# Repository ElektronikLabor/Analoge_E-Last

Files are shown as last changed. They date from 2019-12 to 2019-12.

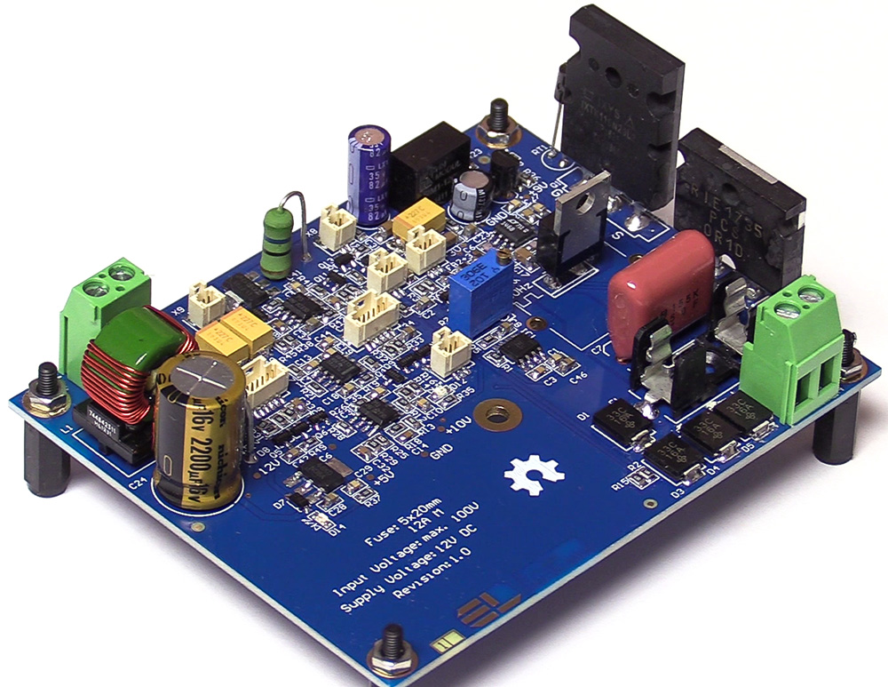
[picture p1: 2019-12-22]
Elektronik/E-Last_PCB_v1.0.jpg

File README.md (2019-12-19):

# Analoge_E-Last
Dies sind die Designdaten für eine analoge elektronische Last für 100V, 10A, 250W.
Das Projekt ist noch in Arbeit.

Der Schaltplan und das Layout sind erstellt mit dem Programm CircuitStudio von Altium

Weitere Infos: https://www.youtube.com/playlist?list=PLRvXcks5uT1ig3Mo9a-mfzwRX9TL_j7m5

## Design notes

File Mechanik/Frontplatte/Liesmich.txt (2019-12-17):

Bestellbar über https://www.schaeffer-ag.de

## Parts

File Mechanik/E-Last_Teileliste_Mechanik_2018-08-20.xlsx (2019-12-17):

 | Teileliste zur analogen E-Last
Pos. | Menge | Bezeichnung | Hersteller | Beschreibung | mögl. Lieferant | Best.-Nr. | Preis/Stk | Notitzen
1 | 1 | IP-6137 | Bud Industries | ABS-Gehäuse | DigiKey | IP-6137-ND | 25.42 €
2 | 1 |  | Schaeffer AG | Frontplatte | Schaeffer AG |  |  | Siehe Frontplatte_v0.1.fpd
3 | 1 | IRM-45-12ST | Mean Well | AC/DC-Wandler 12V 3,8A mit Schraubklemmen | Reichelt | MW IRM-45-12ST | 16.79 €
4 | 1 | WLPF20GR | Fischer Elektronik | Wärmeleitpaste, Metalloxydpulver, 10ml-Spritze | Reichelt | LEITPASTE 20GR | 4.40 €
5 | 1 | 930757100 | Hirschmann | Sicherheitspolklemme, 4 mm, schwarz | Reichelt | PKI 100 SW | 1.80 €
6 | 1 | 930757101 | Hirschmann | Sicherheitspolklemme, 4 mm, rot | Reichelt | PKI 100 RT | 1.80 €
7 | 1 | 10038545 | Fischer Elektronik | Hohlrippen-Lüfteraggregat 12 Volt DC | Reichelt | LA 6100 12V | 55.40 €
8 | 1 | 073392 | BKL | C8 Einbaustecker | Reichelt | B-AC 073392 | 1.60 €
9 | 2 | DPM 535/2 | Schwille | Einbaumessinstrument 2V | eBay
10 | 1 | LD 34 S | Knitter | Signalleuchte rot 2,2V | Distrelec | 300-39-844 | 7.29 €
11 | 1 | 1855.1108 | Marquardt | Wippschalter DPST 250V | Conrad | 700592 - 62 | 5.19 €
12 | 1 | M2012SS1W01 | NKK | Kippschalter SPDt 30V 3A M6 | DigiKey | 360-1801-ND | 3.02 €
13 | 1 | M2024SS1G01 | NKK | Kippschalter SP3T 30V M6 | DigiKey | 360-1856-ND | 6.15 €
14 | 1 | BT 81 6M | Atoms | Poti-Drehknopf 10-Gang 6mm | RS | 107-7253 | 12.08 €
15 | 1 | 3590s-002-502 | Bourns | 10-Gang-Potetiometer 0,25% | DigiKey | 3590S-2-502L-ND | 12.20 €
16 | 2 | 14.86.353 | Ettinger | Montagewinkel 12,0 x 15,0 x 1,5 mm | Ettinger | 14.86.353 | 2.18 €
17 |  | …
⁞

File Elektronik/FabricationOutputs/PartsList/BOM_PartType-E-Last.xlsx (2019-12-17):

E-Last |  |  |  |  |  | Component Count | 149 | 16.12.2019 | 19:43:20
# | Quantity | Designator | Value | Description | Manufacturer | PartNumber | Supplier 1 | Supplier Part Number 1 | Price [€]
1 | 13 | C1, C10, C11, C16, C18, C19, C27, C29, C31, C35, C41, C42, C44 | 100n | Cap Ceramic 0805 100n 25V | generic | generic
2 | 2 | C2, C36 | 220n | Cap Ceramic 0805 220n 50V | generic | generic
3 | 3 | C3, C12, C17 | 10n | Cap Ceramic 0805 10n 50V | generic | generic
4 | 3 | C4, C38, C39 | 330p | Cap Ceramic 0805 330p 50V | generic | generic |  |  | 0,18
5 | 2 | C5, C9 | 220p | Cap Ceramic 0805 220p 50V | generic | generic
6 | 1 | C6 | 100p | Cap Ceramic 0805 100p 50V | generic | generic
7 | 1 | C7 | 1µ5 | Cap Film 1µ5 250V 15mm | Panasonic | ECQE2155KF
8 | 5 | C8, C23, C33, C34, C46 | 1µ | Cap Ceramic 0805 1µ 25V | Samsung | CL21B105KAFNNNE | Digi-Key | 1276-1066-1-ND
9 | 1 | C13 | 1n5 | Cap Ceramic 0805 1n5 50V | generic | generic
10 | 2 | C14, C32 | 3n3 | Cap Ceramic 0805 3n3 50V | generic | generic
11 | 3 | C15, C21, C30 | 10µ | Cap Ceramic 1206 10µ 16V | Samsung | CL31B106MOHNNNE | Digi-Key | 1276-6641-1-ND | 0,13
12 | 1 | C20 | 100µ | Cap Elco 100µ Radial | Nichicon | UMA0J101MDD
13 | 3 | C22, C40, C43 | 220µ | Cap Tantal 220µ 16V SMD | AVX | TPSE227*016#0100 | Reichelt | TPS 7343 220/16 | 1,15
14 | 1 | C24 | 2200µ | Cap Elco 2200µ 16V THT Radial | Rubycon | UFW1C222MHD | Digi-Key | 493-15122-ND | 0.77
15 | 1 | C25 | 82µ | Cap Elco 82µ Radial | Nippon Chemi-Con | ELXY350ETD820MF15D
16 | 2 | C26, C28 | 330n | Cap Ceramic 0805 330n 50V | Samsung | CL21B334KBFNNNE | Digi-Key | 1276-1123-1-ND | 0,18
17 | 1 | C37 | 4µ7 | Cap Ceramic 0805 4µ7 10V | generic | generic
18 | 1 | C45 | 1n | Cap Ceramic 0805 1n 50V | generic | generic
19 | 4 | D1, D3, D4, D5 | 1.5SMC33CA | Diode, TVS, Bi, 33V, 33A, DO-214AB | Littelfuse | 1.5SMC33CA
20 | 1 | D2 | 12TQ150 | Diode Schottky, 150V, 15A, TO-220-2 | SMC | 12TQ150 | Digi-Key | 1655-1002-ND | 0,61
21 | 2 | D6, D7 | BAV19W | Diode, Fast, 400mA, SOD-123, SMD | Diodes | BAV19W-E3-08
22 | 1 | D8 | 1.5KE22A | Diode, TVS, Uni, 22V, CB429, THT | ST | 1.5KE22A | Reichelt | 1,5KE 22A
23 | 1 | D9 |  | LED Red 0805 SMD | Würth Elektronik | 150080SS75000 | Digi-Key | 732-4985-1-ND | 0,18
24 | 1 | D10 | 10V | V-Ref LM4040AIM3-10.0 | Texas Instruments | LM4040AIM3-10.0/NOPB | Digi-Key | LM4040AIM3-10.0/NOPBCT-ND | 1,53
25 | 3 | D11, D13, D14 |  | LED Blue 0805 SMD | Würth Elektronik | 150080BS75000 | Digi-Key | 732-4982-1-ND | 0,18
26 | 1 | D12 |  | LED Green 0805 SMD | Generic | Generic
27 | 1 | F1 | 12A | Fuse w Holder 5x20mm 25mm 12A THT | Schurter | 0031.8211 | Reichelt | PL OGN-25 | 0,44
28 | 3 | FB1, FB2, FB3 | 1k | Ferrite Bead 0805 1k 100MHz | Murata | BLM21AG102SN1 | Reichelt | BLM21AG 102
29 | 1 | HS1 |  | Mech Heat Sink CK960/20/SE TO-220; Unfertig | Alutronic | CK960/20/SE | Reichelt | V CK960/20
30 | 1 | IC1 | ICM7555 | Timer ICM7555 8-SOIC | Intersil | ICM7555IBA | Reichelt | ICM 7555 IBAZ
31 | 1 | IC2 | LT1468 | OpAmp LT1468 1x 90MHz | Linear Technology | LT1468CS8 | Reichelt | LT 1468 CS8 | 7,05
32 | 2 | IC3, IC7 | LM393 | Comparator LM393DT 2x | ST | LM393DT | Digi-Key | 497-1593-1-ND | 0,44
33 | 1 | IC4 | TL072C | OpAmp TL072CD 2x JFET 3MHz | Texas Instruments | TL072CD
34 | 1 | IC5 | 78L09 | Voltage Regulator 9V | ST | L78L09ACZ
35 | 1 | IC6 | LM1117 | Voltage Regulator 5V SOT-223 | Texas Instruments | L7805CV | Reichelt | LM 1117 MPX-5.0
36 | 1 | L1 | 110µ | Common Mode Choke, WE-CMB Type S, 110 uH | Würth Elektronik | 744842311
37 | 1 | L2 | 12µ | Inductor 12µ 7447669112 SMD | Würth Elektronik | 7447669112 | Digi-Key | 732-7321-1-ND | 0,43
38 | 1 | Q1 | IXTK110N20L2 | Transistor n-MOS, TO-264, 200V, THT | IXYS | IXTK110N20L2 | Digi-Key | IXTK110N20L2-ND | 24,00
39 | 11 | Q2, Q3, Q4, Q5, Q6, Q7, Q8, Q9, Q10, Q11, Q13 |  | Transistor n-MOS SOT-23 30V Vgs=20V | ON Semiconductor | NDS355AN | Digi-Key | NDS355ANCT-ND | 0,39
40 | 1 | Q12 | IRLL2705 | Transistor n-MOS SOT-223 55V Vgs=16V | International Rectifier | IRLL2705PbF | Reichelt | IRLL 2705 | 0,44
41 | 7 | R1, R11, R14, R20, R26, R39, R41 | 18k | Resistor 0805 18k | generic | generic
42 | 2 | R2, R45 | 5k1 | Resistor 0805 5k1 | generic | generic
43 | 2 | R3, R36 | 5k6 | Resistor 0805 5k6 | generic | generic
44 | 1 | R4 | 100R | Resistor 0805 100R | generic | generic
45 | 2 | R5, R34 | 6k8 | Resistor 0805 6k8 | generic | generic
46 | 2 | R6, R44 | 39k | Resistor 0805 39k | generic | generic
47 | 1 | R7 | 1k | Pot 1k THT 30 turns | Suntan | TSR-3296-Y-102-R
48 | 1 | R8 | 10R | Resistor 0805 10R | generic | generic
49 | 2 | R9, R16 | 1k | Resistor 0805 1k | generic | generic
50 | 1 | R10 | 0R1 | Resistor 4-SIL 0R1 0.5% 40W | Riedon | PCS-0R1D1 | Digi-Key | 696-1749-ND | 15,91
51 | 1 | R12 | 5M6 | Resistor 0805 5M6 | generic | generic
52 | 1 | R13 | 91k | Resistor 0805 91k | generic | generic
53 | 1 | R15 | 1M8 | Resistor 0805 1M8 | generic | generic
54 | 2 | R17, R21 | 200k | Resistor 0805 200k | generic | generic
55 | 3 | R18, R47, R49 | 1k8 | Resistor 0805 1k8 | generic | generic
56 | 2 | R19, R37 | 2k | Resistor 0805 2k | generic | generic
57 | 1 | R22 | 2R2 | Resistor 0805 2R2 | generic | generic
58 | 1 | R23 | 220R | Resistor 0805 220R | generic | generic
59 | 1 | R24 | 270R | Resistor 0805 270R | generic | generic
60 | 1 | R25 | 62k | Resistor 0805 62k | generic | generic
61 | 1 | R27 | 4M3 | Resistor 0805 4M3 | generic | generic
62 | 1 | R28 | 10M | Resistor 0805 10M | generic | generic
63 | 2 | R29, R50 | 15k | Resistor 0805 15k | generic | generic
64 | 6 | R30, R31, R32, R33, R35, R42 | 4k7 | Resistor 0805 4k7 | generic | generic
65 | 2 | R38, R40 | 10k | Resistor 0805 10k | generic | generic
66 | 1 | R43 | 82k | Resistor 0805 82k | generic | generic
67 | 1 | R46 | 6k98 | Resistor 0805 6k98 | generic | generic
68 | 1 | R48 | 56R | Resistor 56R 2W THT | VITROHM | PO593-0 5 T 56R | Reichelt | 2W METALL 56 | 0,11
69 | 1 | R51 | 4M7 | Resistor 0805 4M7 | generic | generic
70 | 1 | RT1 | 2k | Sensor Temp 2k TO92-2 | NXP | KTY81/222 | Conrad | 181048 - 62 | 2,05
71 | 1 | VR1 | SIM1-1203 | DC/DC Converter Isolated 3V | HN Electronic Components | SIM1-1203-SIL4
72 | 3 | X1, X2, X3 | T1M-03-F-SV-L | Connector, Male, Vertical, 3-Pin, 1mm, SMD | SAMTEC | T1M-03-F-SV-L | SAMTEC | T1M-03-F-SV-L
73 | 2 | X4, X5 |  | Terminal, 2-Pin, 5.08mm, THT | RND connect | RND 205-00287 | Reichelt | RND 205-00287 | 0,41
74 | 2 | X6, X7 | T1M-06-F-SV-L | Connector, Male, Vertical, 6-Pin, 1mm, SMD | SAMTEC | T1M-06-F-SV-L | SAMTEC | T1M-06-F-SV-L
75 | 2 | X8, X9 | T1M-02-F-SV-L | Connector, Male, Vertical, 2-Pin, 1mm, SMD | SAMTEC | T1M-02-F-SV-L | SAMTEC | T1M-02-F-SV-L

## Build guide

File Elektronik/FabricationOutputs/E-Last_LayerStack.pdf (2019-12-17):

Layer | Board Layer Stack | Name | Material | Thickness | Constant

# Board Stack Report

Stack Up | Layer Stack

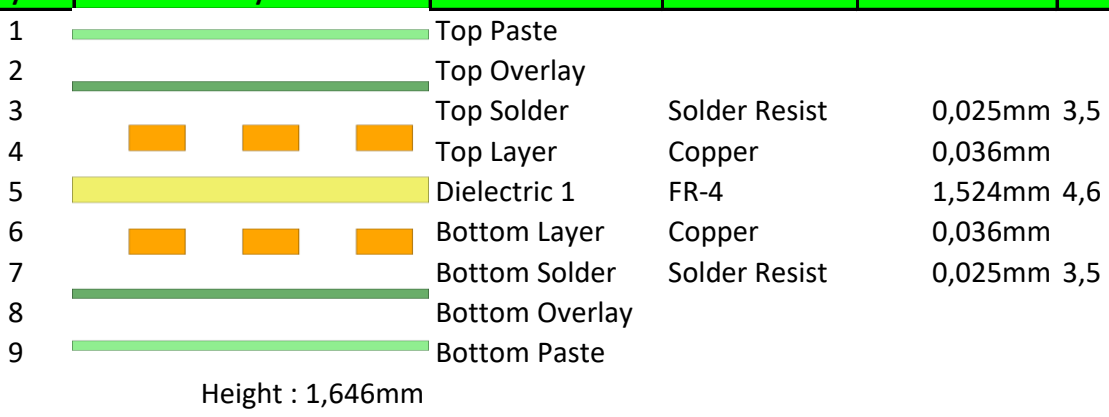
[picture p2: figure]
Top Paste; Top Overlay; Top Solder; Solder Resist; Top Layer; Copper; Dielectric 1; Bottom Layer; Bottom Solder; Bottom Overlay; Bottom Paste; Height : 1,646mm

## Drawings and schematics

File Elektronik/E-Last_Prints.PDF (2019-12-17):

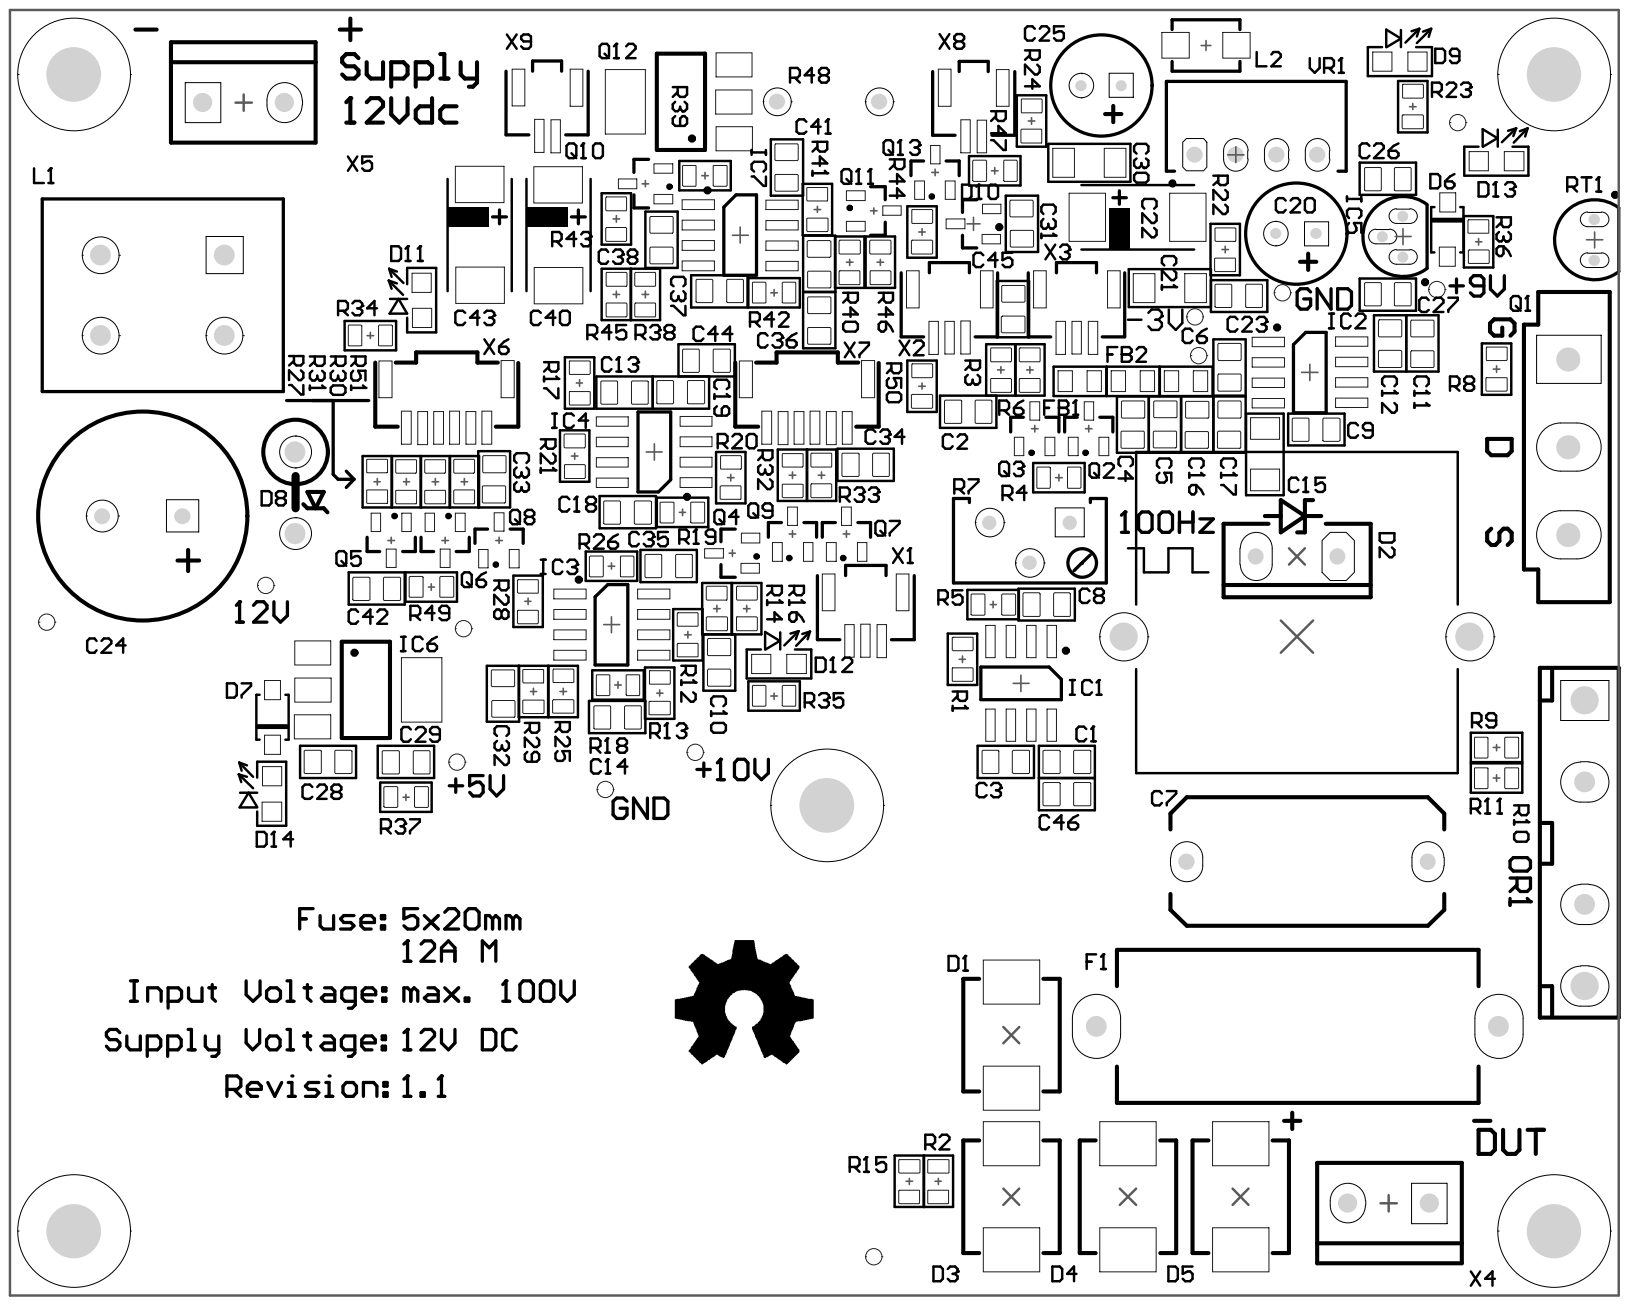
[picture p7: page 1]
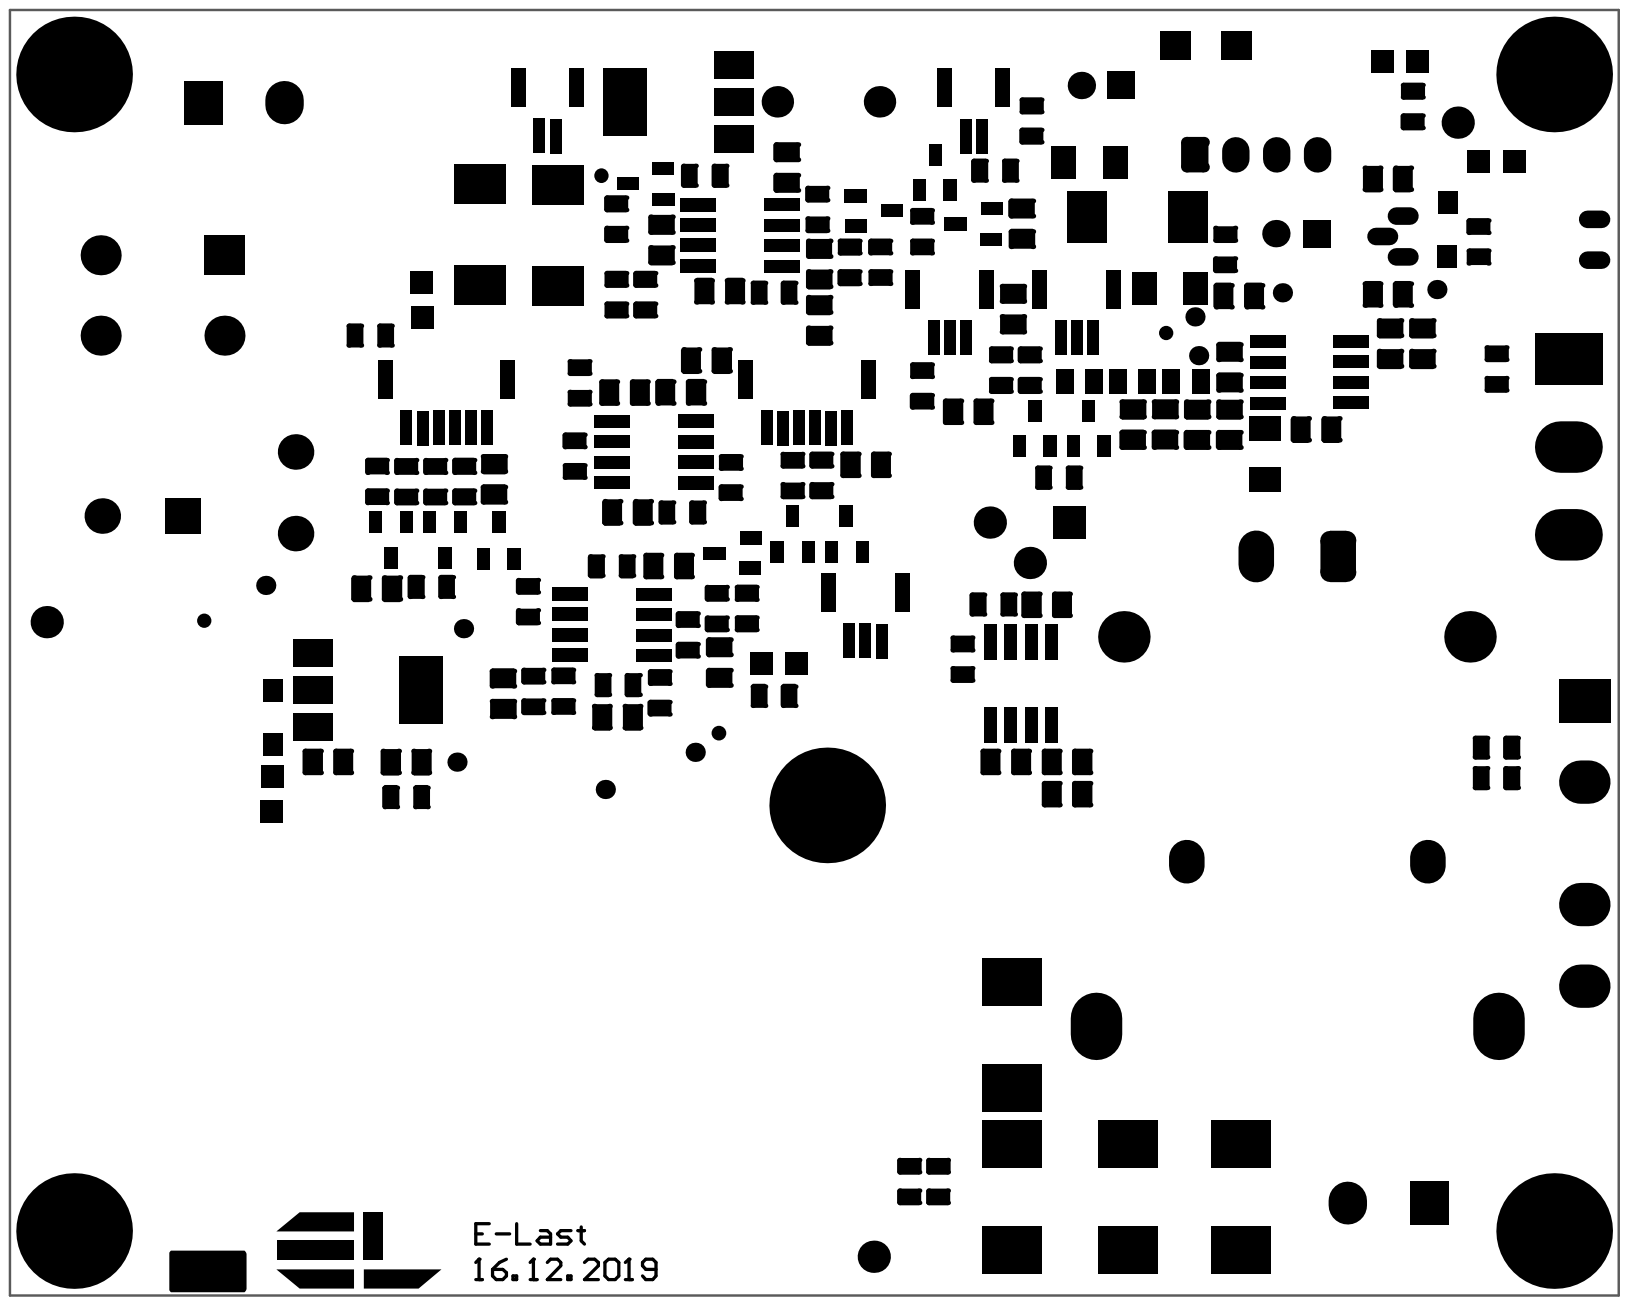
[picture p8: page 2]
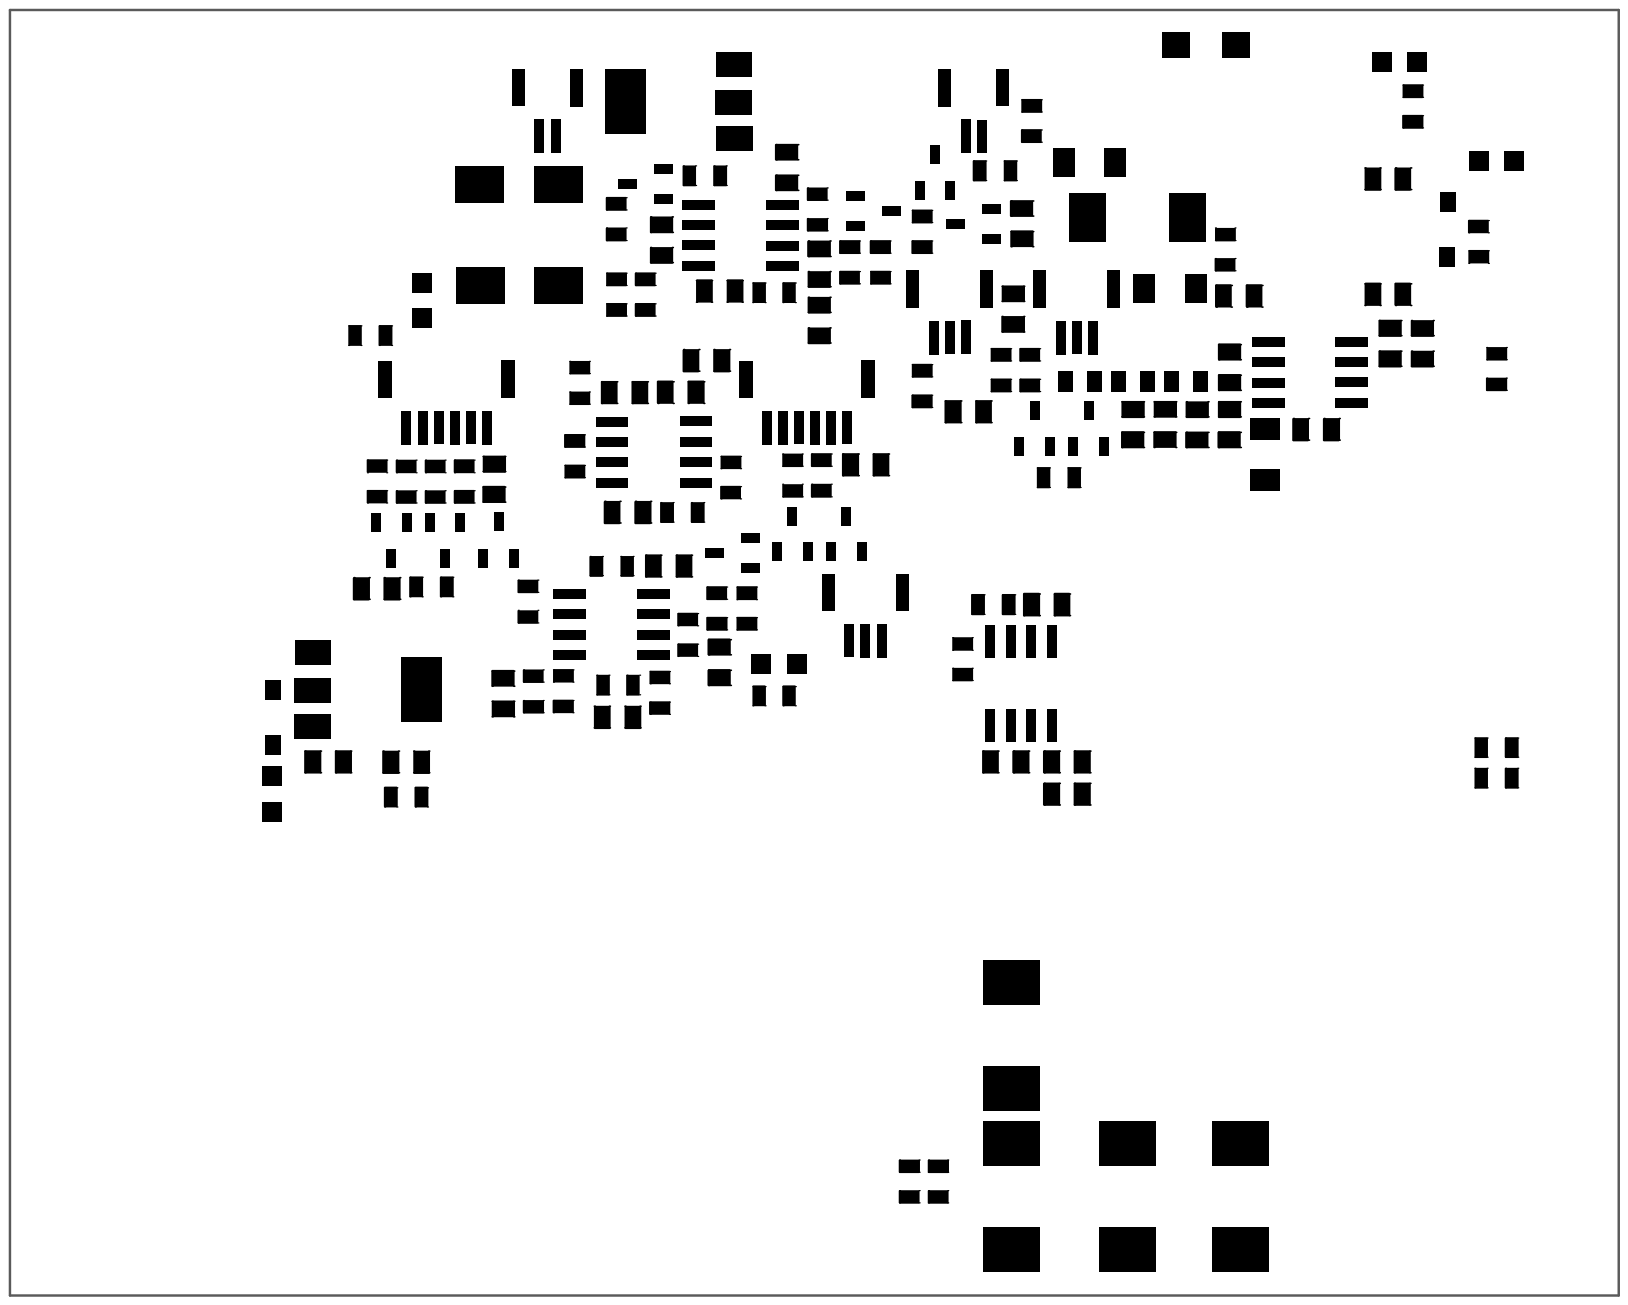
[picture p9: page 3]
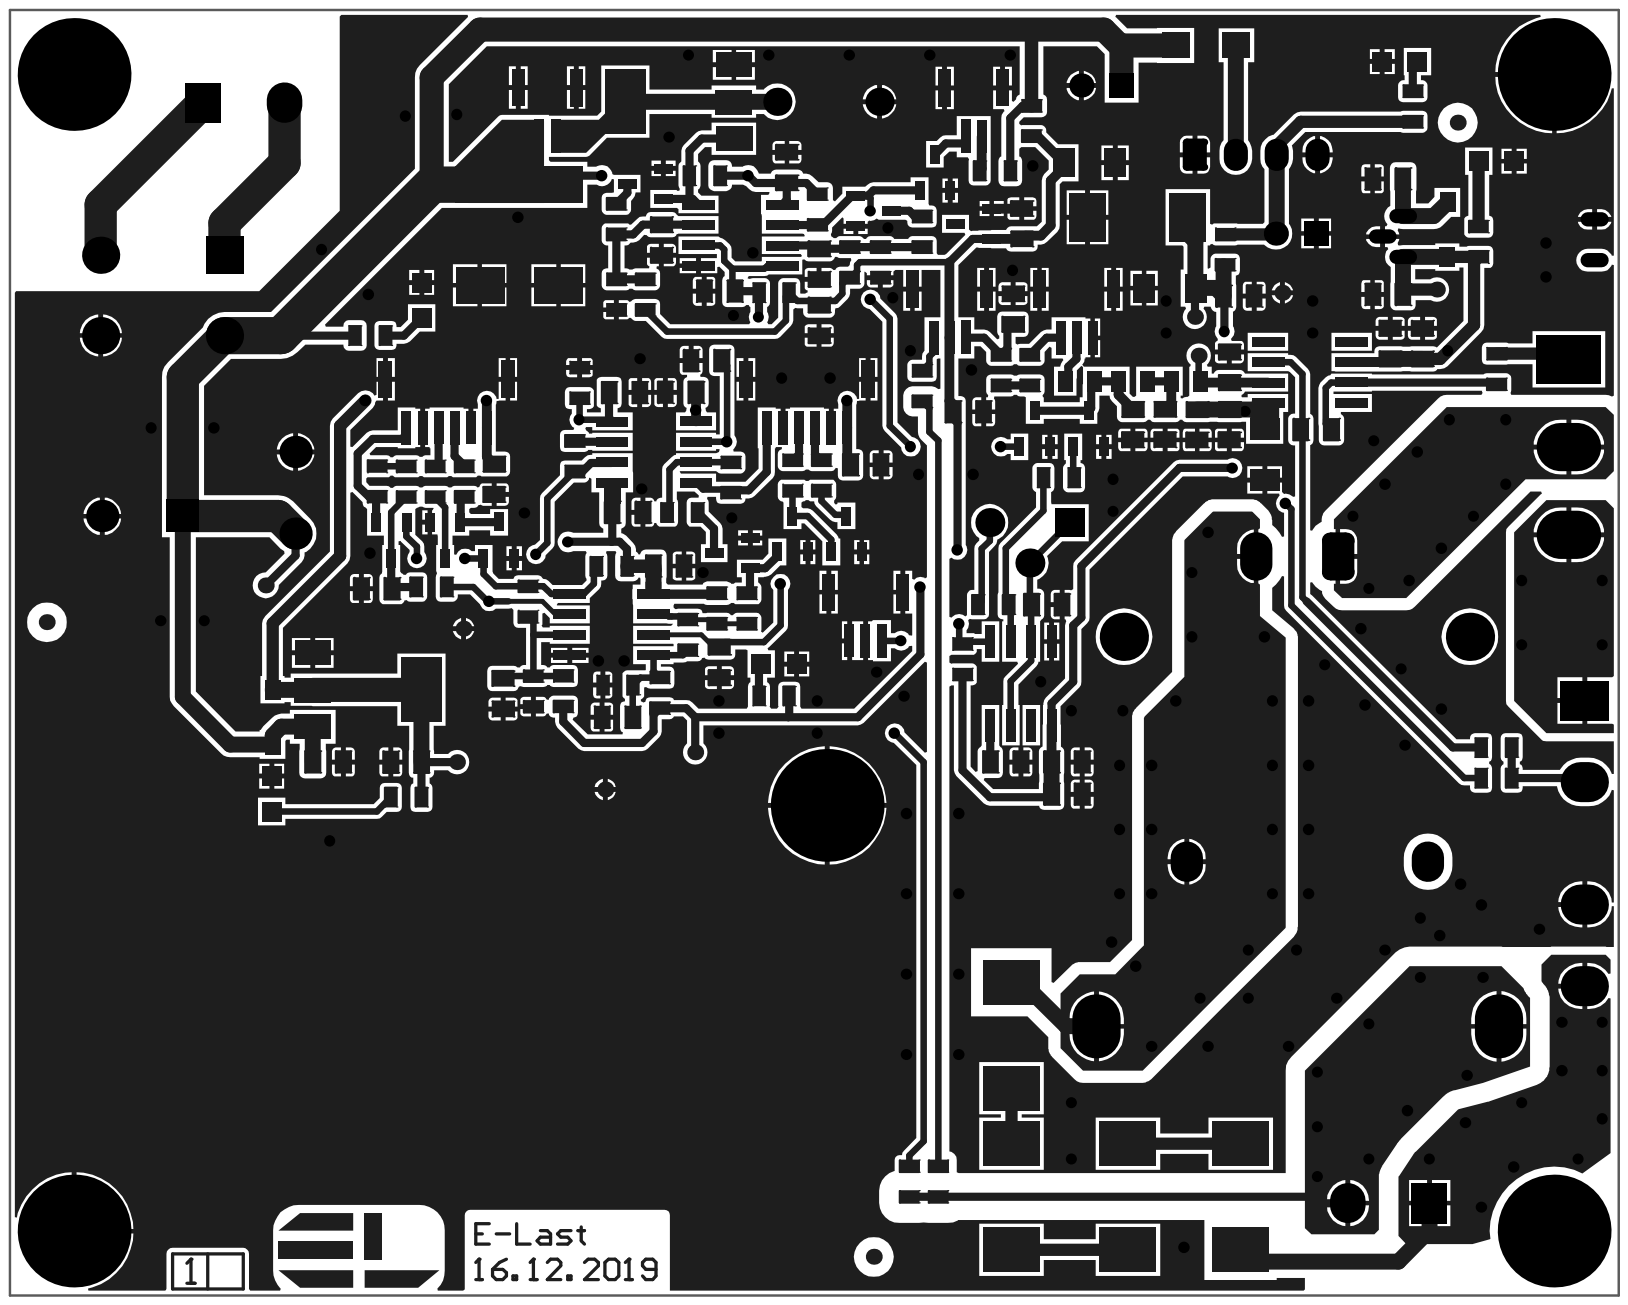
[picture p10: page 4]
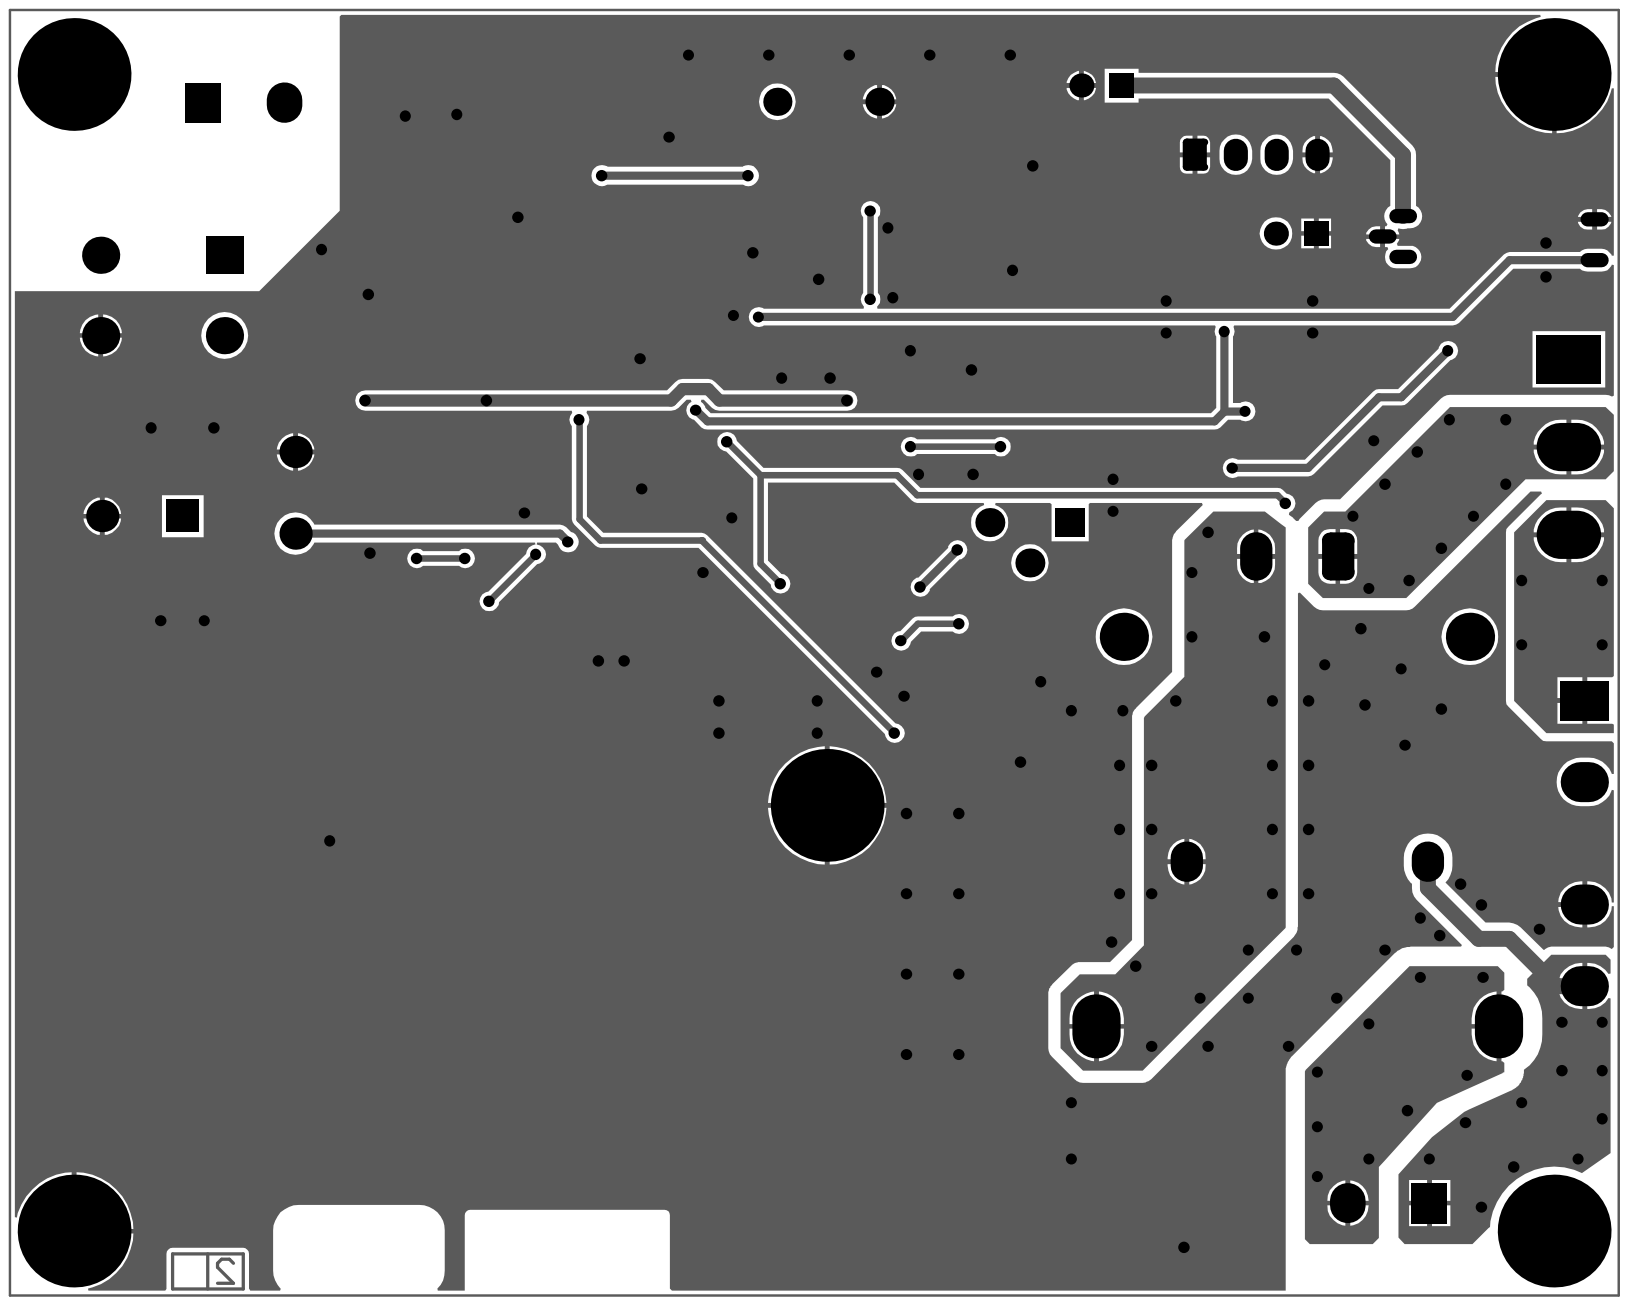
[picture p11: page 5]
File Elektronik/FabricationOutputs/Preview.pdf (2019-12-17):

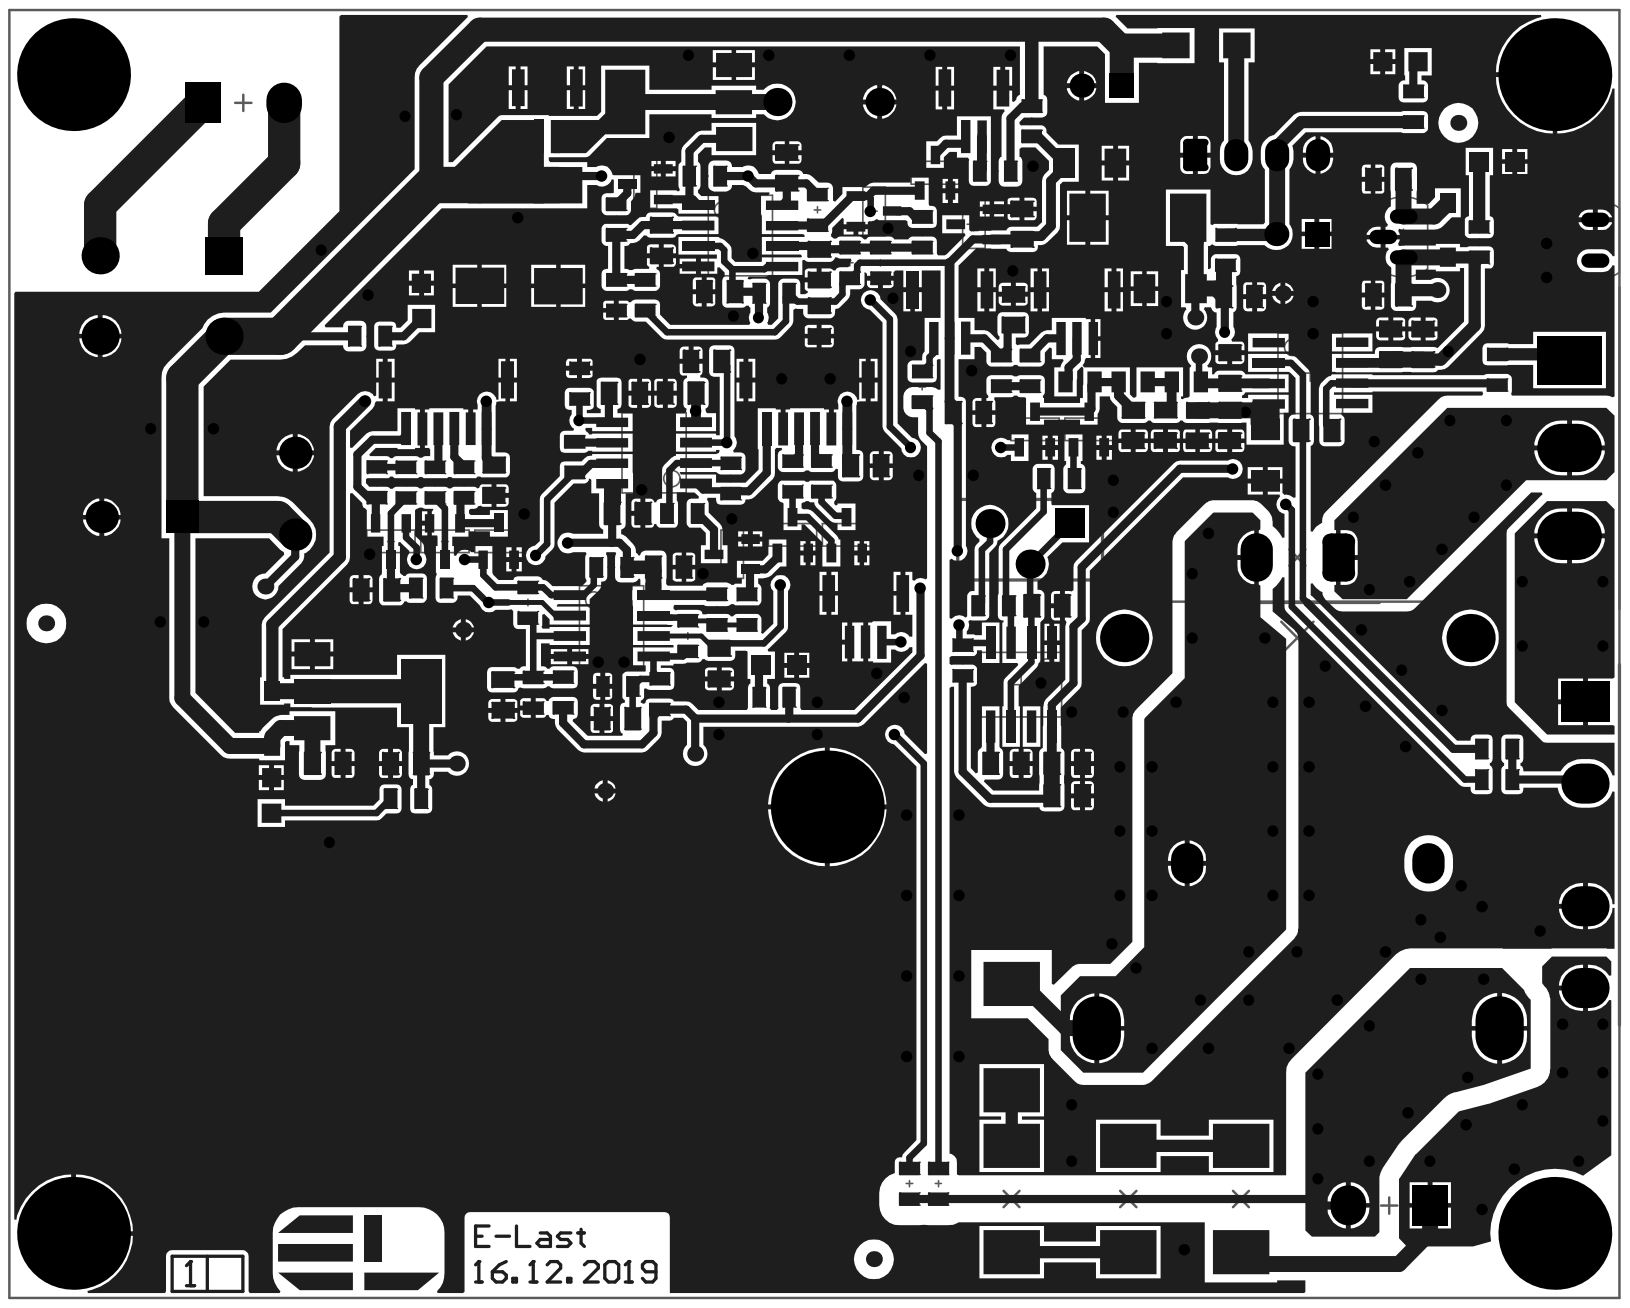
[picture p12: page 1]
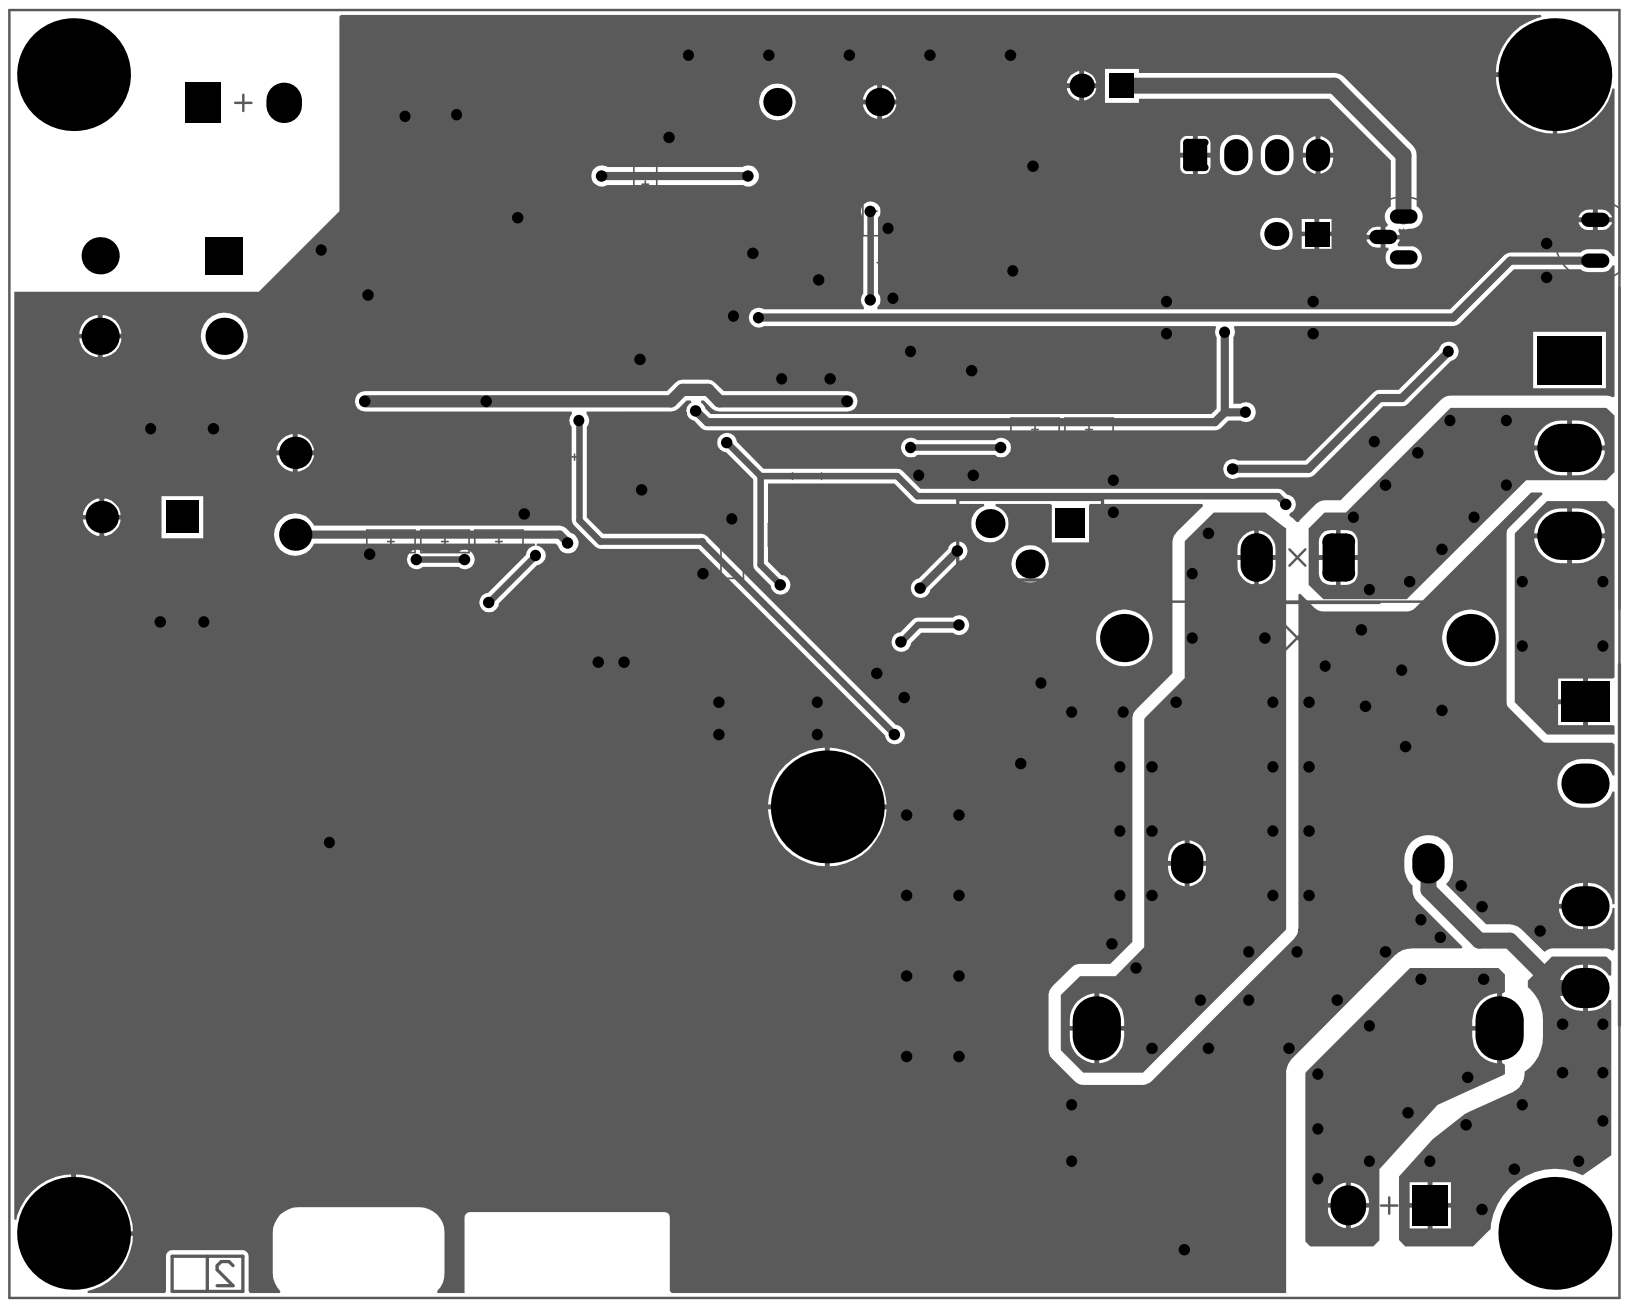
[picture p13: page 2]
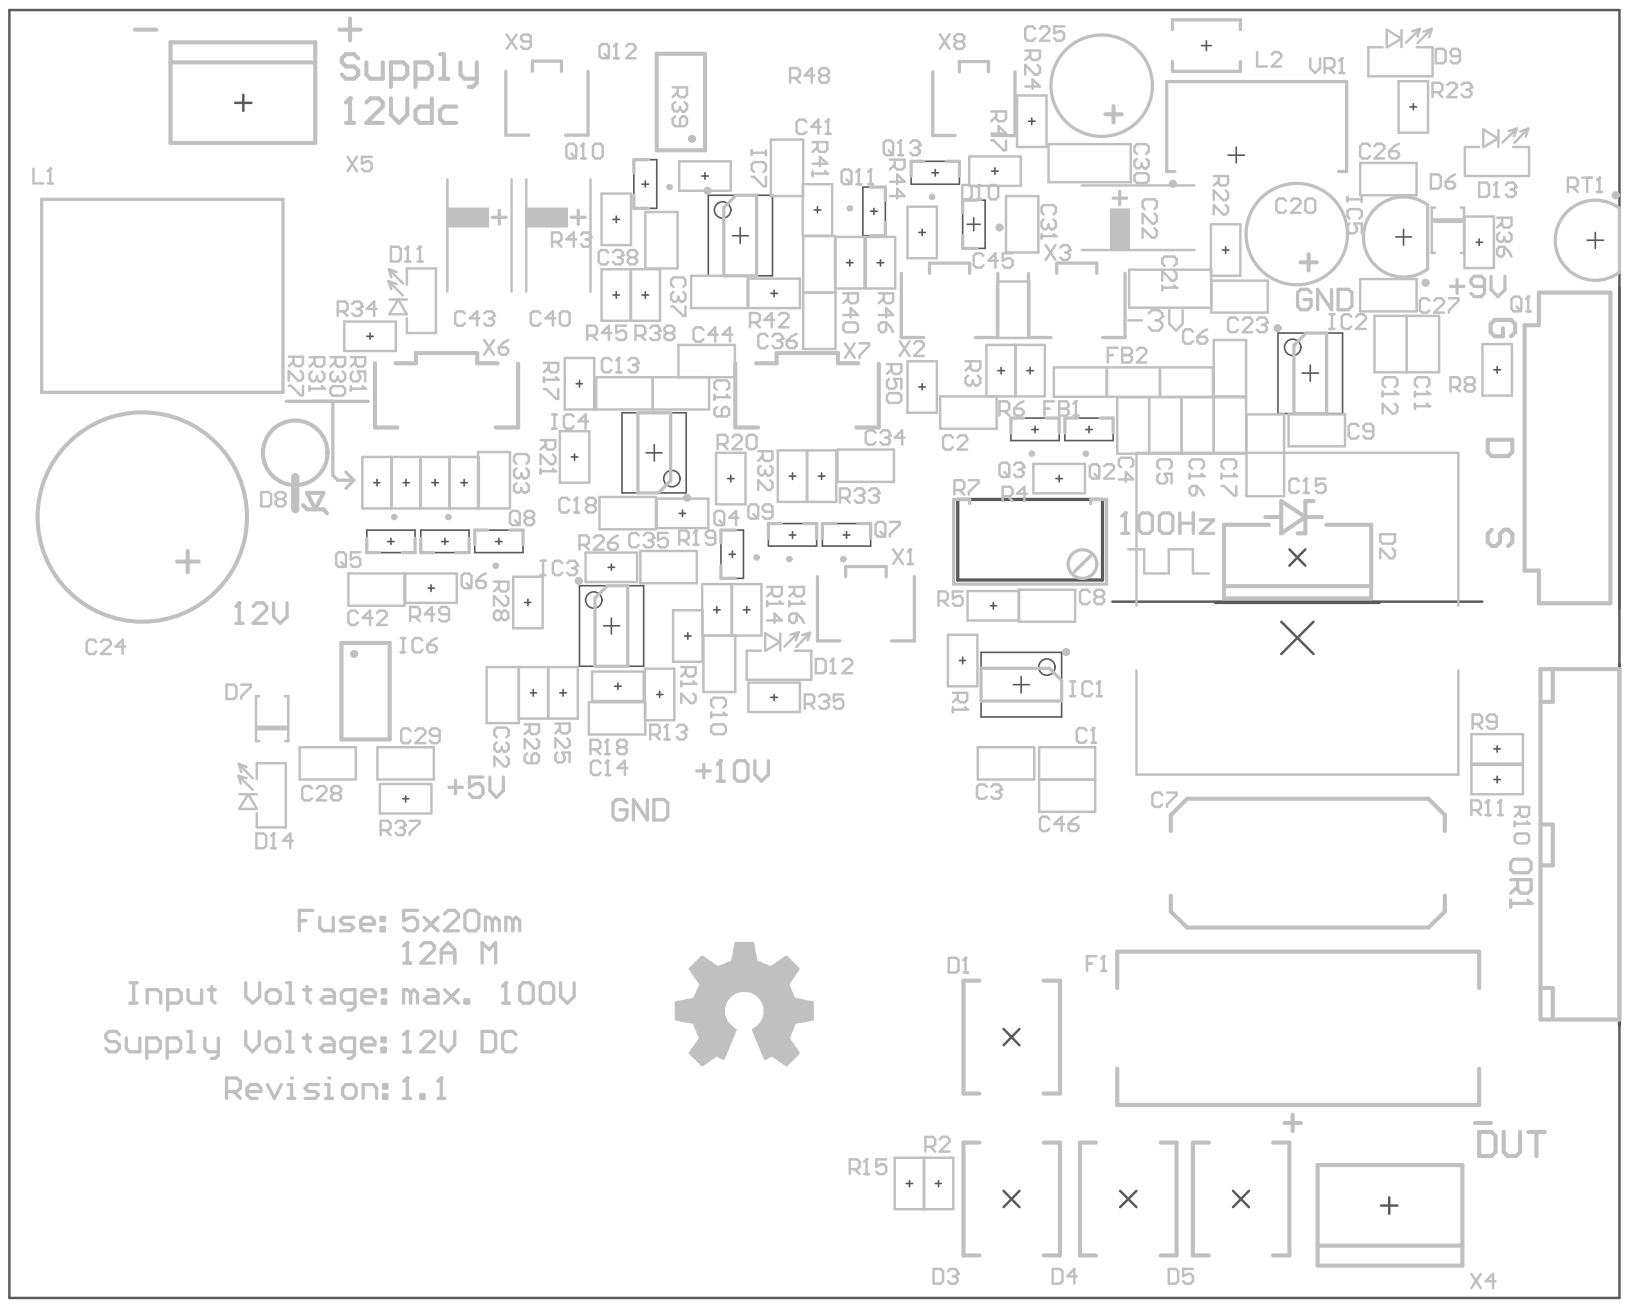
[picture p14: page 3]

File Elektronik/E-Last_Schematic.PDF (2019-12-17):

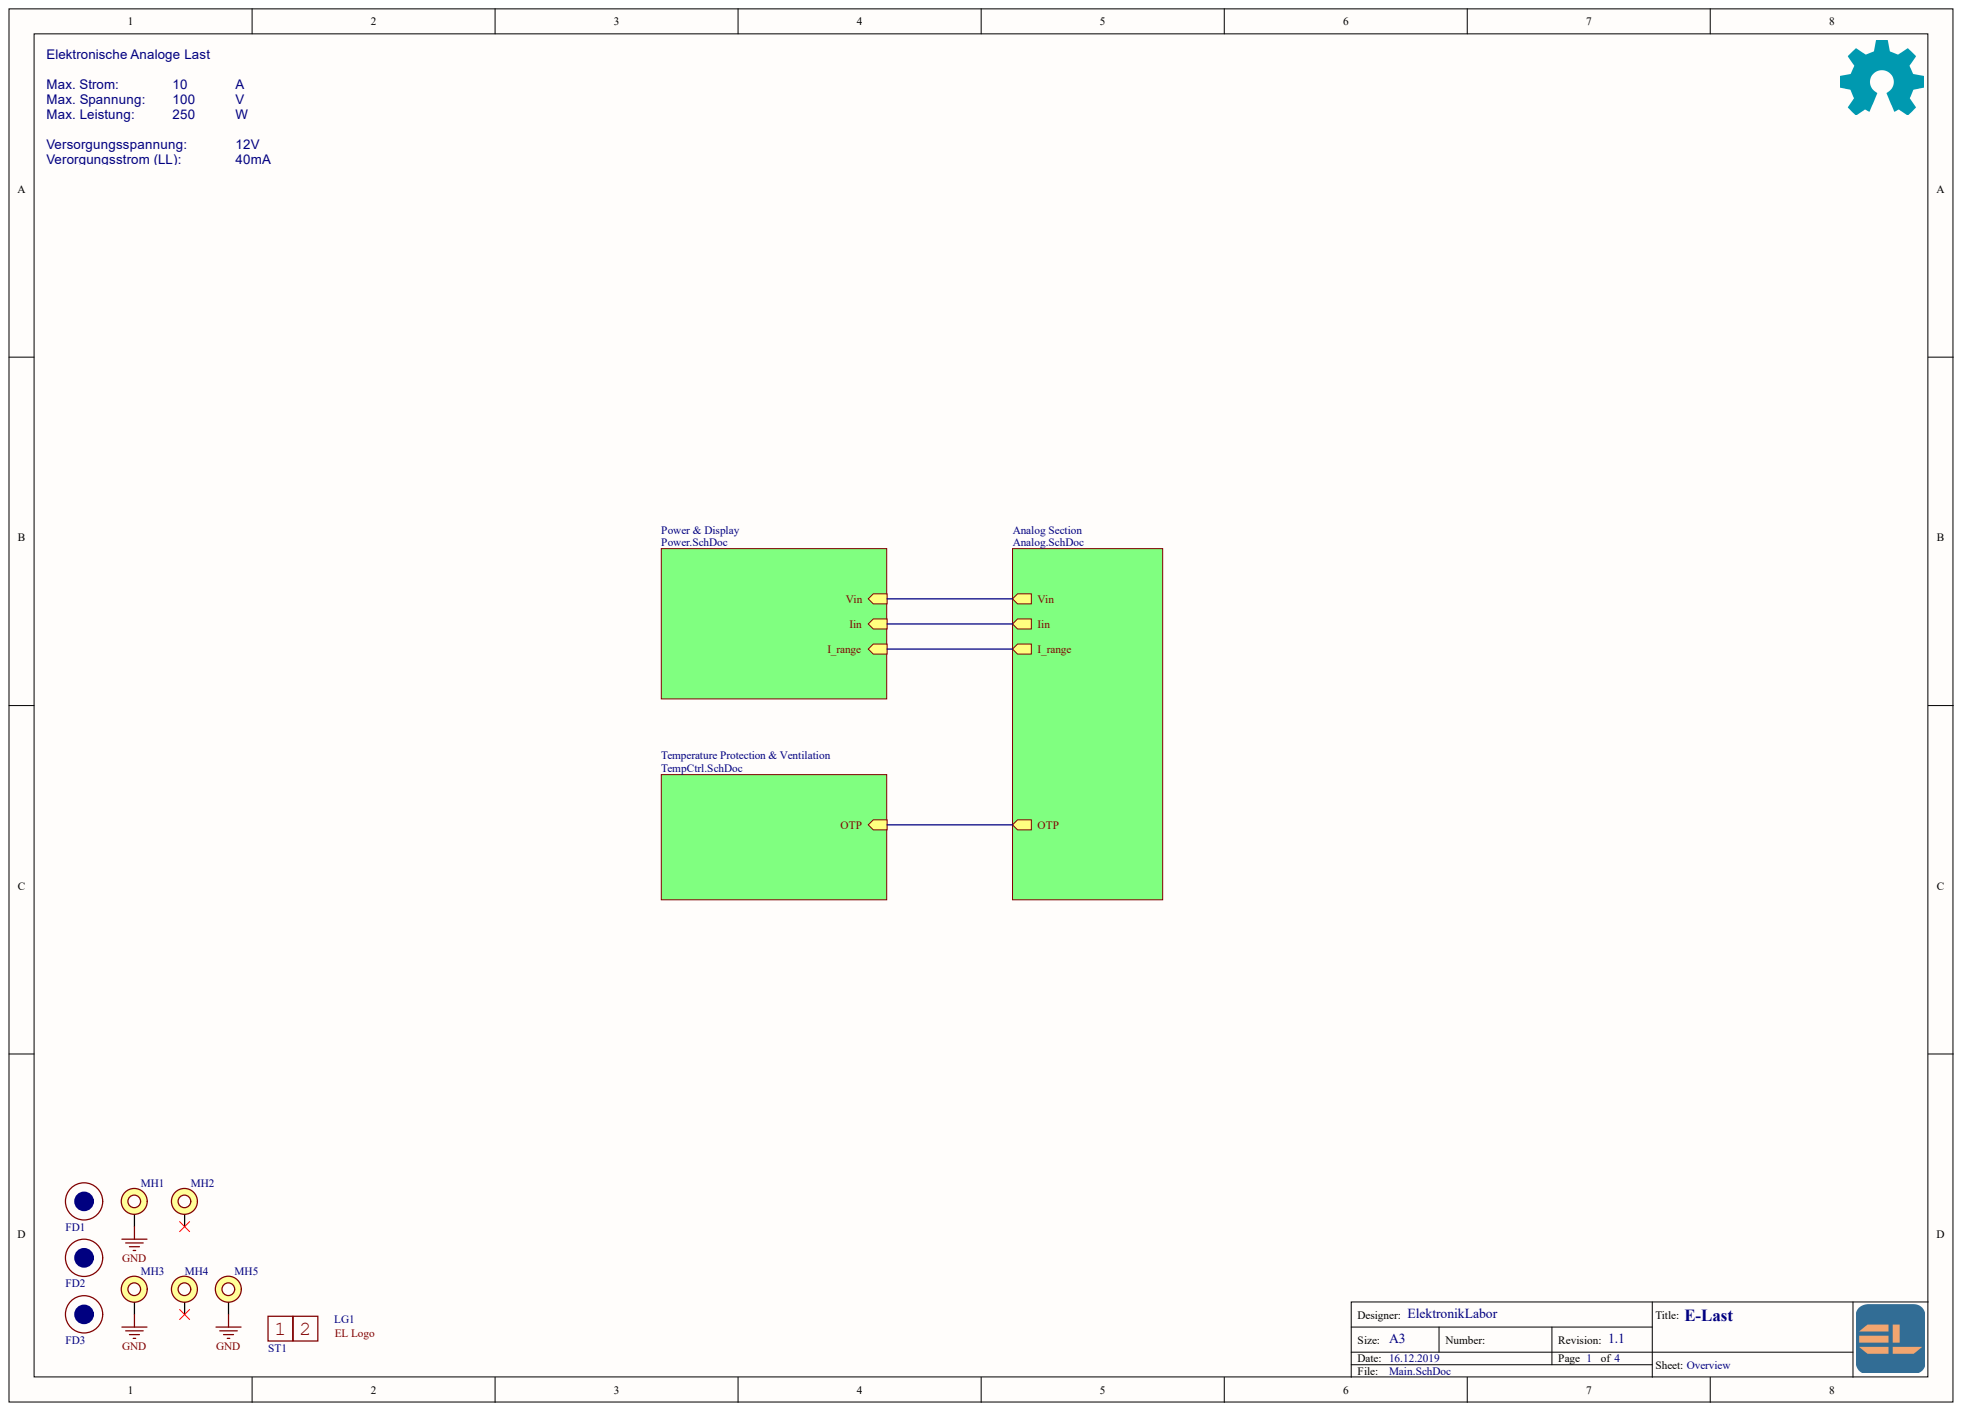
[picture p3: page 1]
Power & Display; Analog Section; Max. Strom:; Max. Spannung:; Max. Leistung:; Verorgungsstrom (LL):; EL Logo

Elektronische Analoge Last

Temperature Protection & Ventilation
TempCtrl.SchDoc

Designer: ElektronikLabor | Title: E-Last

Size: A3 | Number: | Revision:

Date: 16.12.2019 | Page of | Sheet: Overview

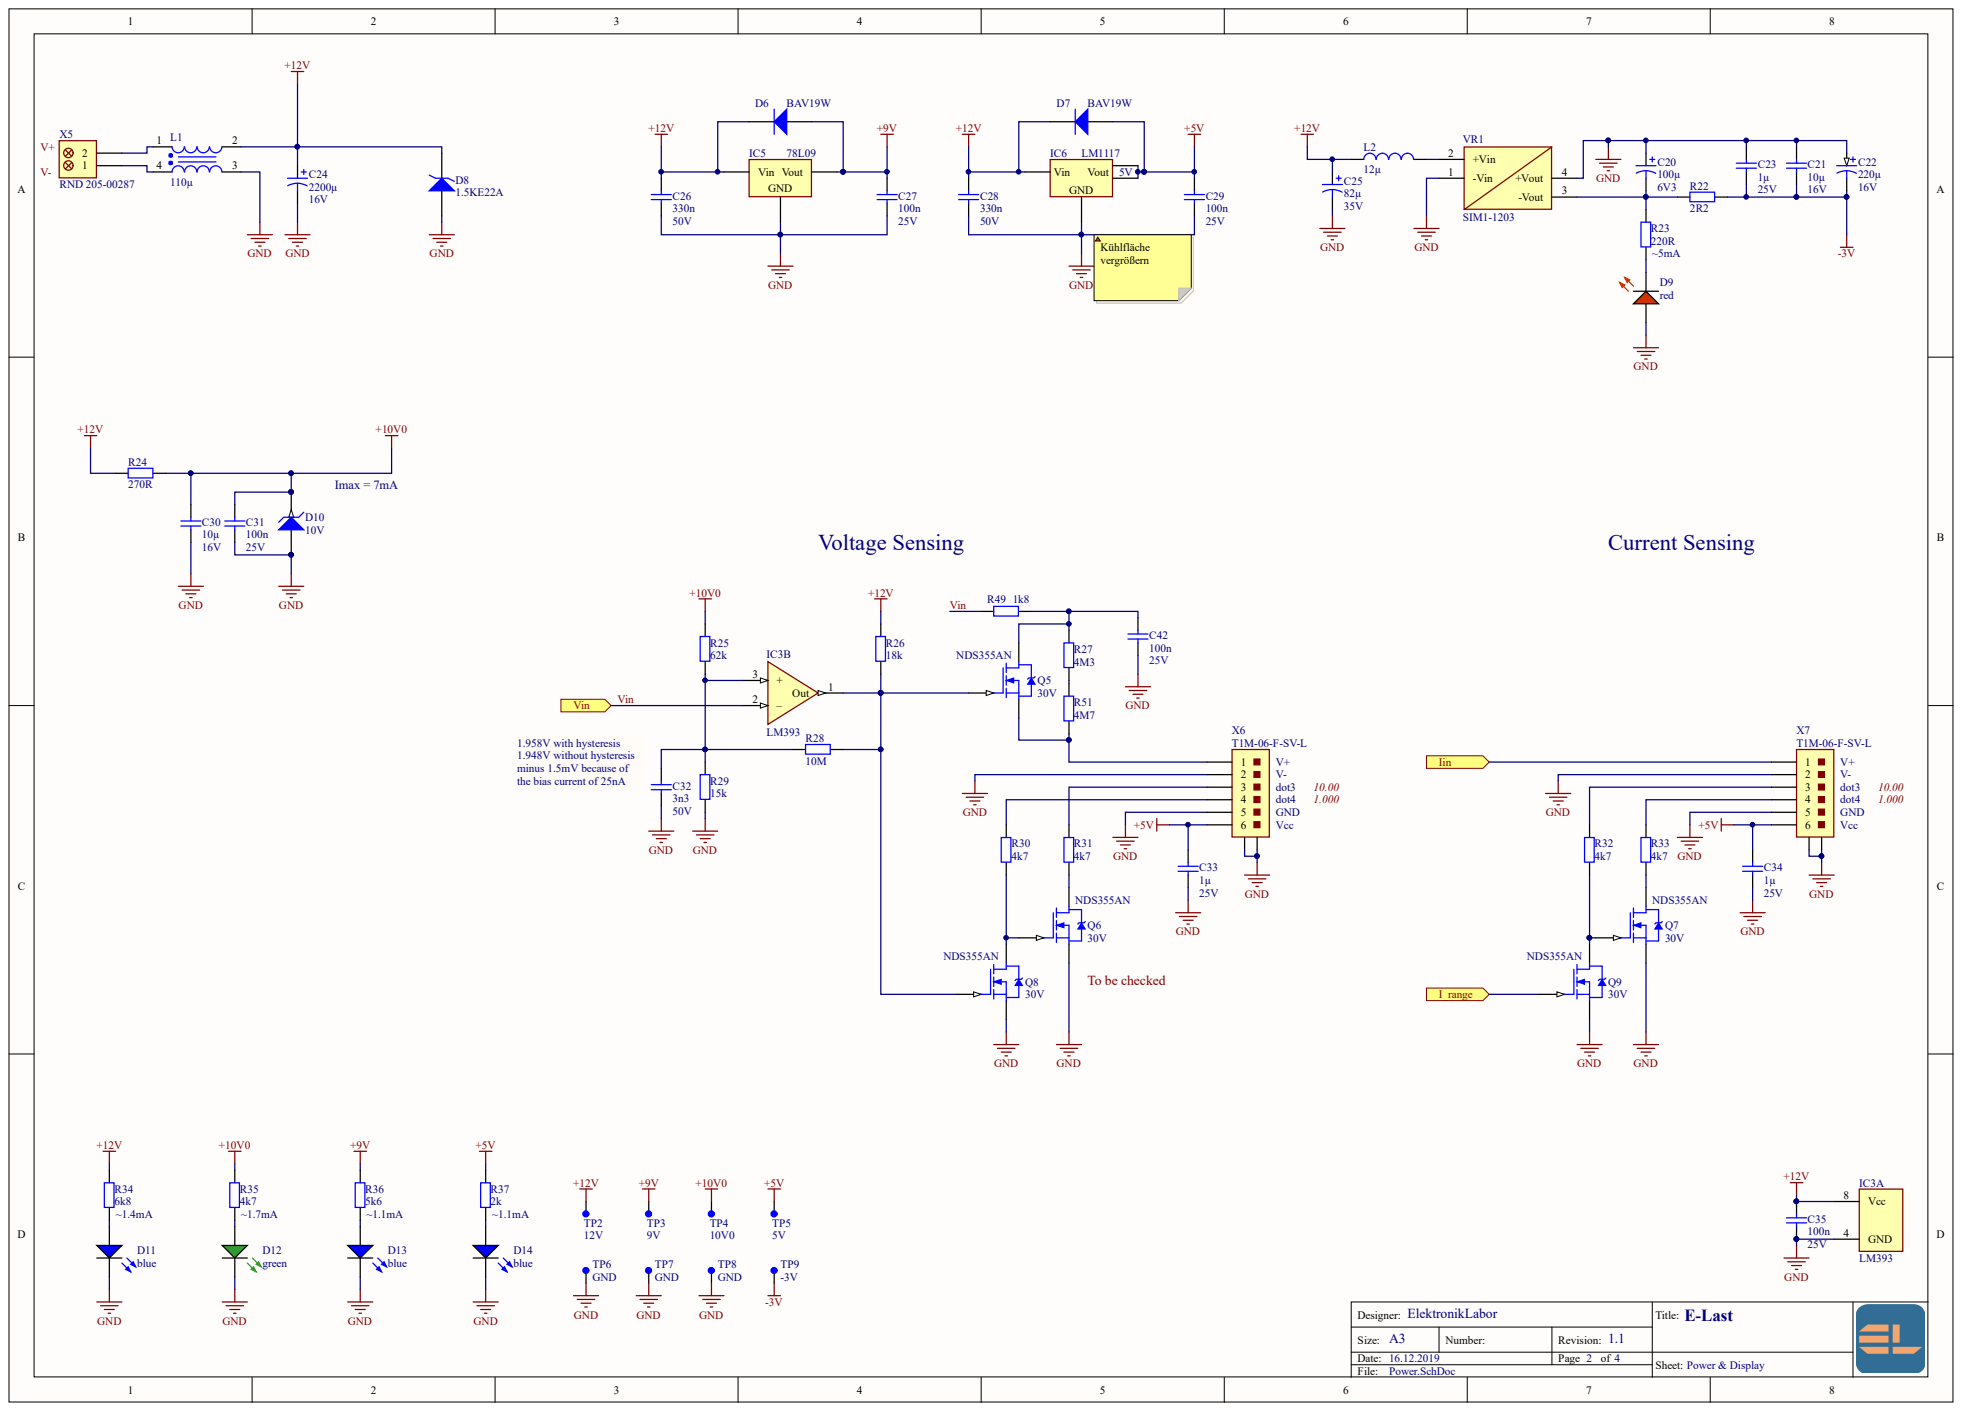
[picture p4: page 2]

1.958V with hysteresis
1.948V without hysteresis
minus 1.5mV because of
the bias current of 25nA

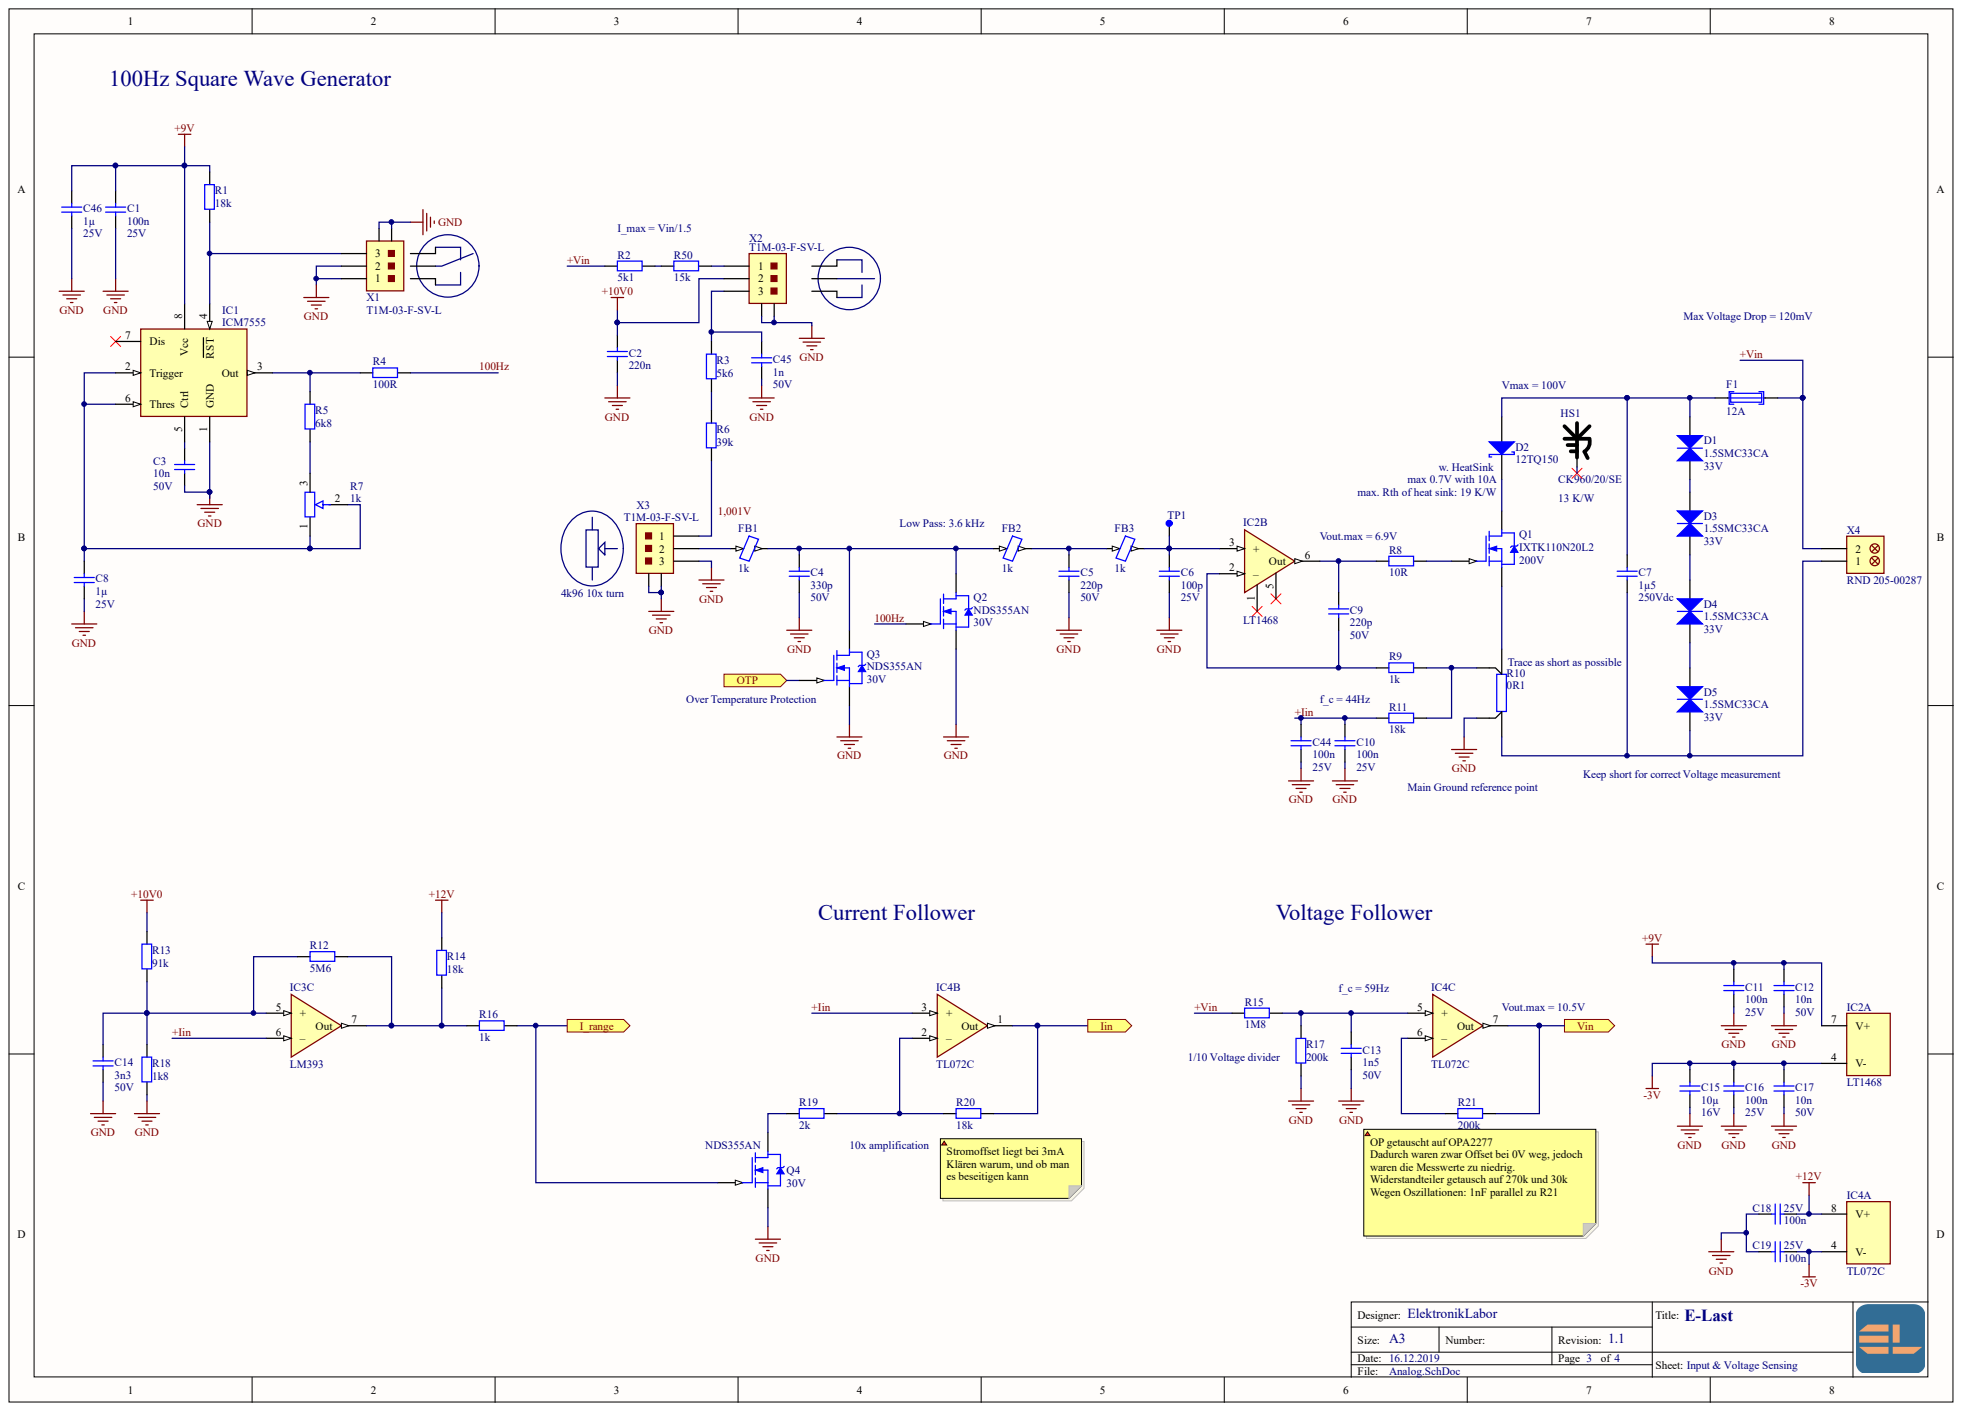
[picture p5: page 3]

Dis 7

Thres 6

13 K/W max. Rth of heat sink: 19 K/W

Keep short for correct Voltage measurement

Main Ground reference point

Stromoffset liegt bei 3mA
Klären warum, und ob man
es beseitigen kann

OP getauscht auf OPA2277
Dadurch waren zwar Offset bei 0V weg, jedoch
waren die Messwerte zu niedrig.
Widerstandteiler getausch auf 270k und 30k
Wegen Oszillationen: 1nF parallel zu R21

Sheet: Input & Voltage Sensing

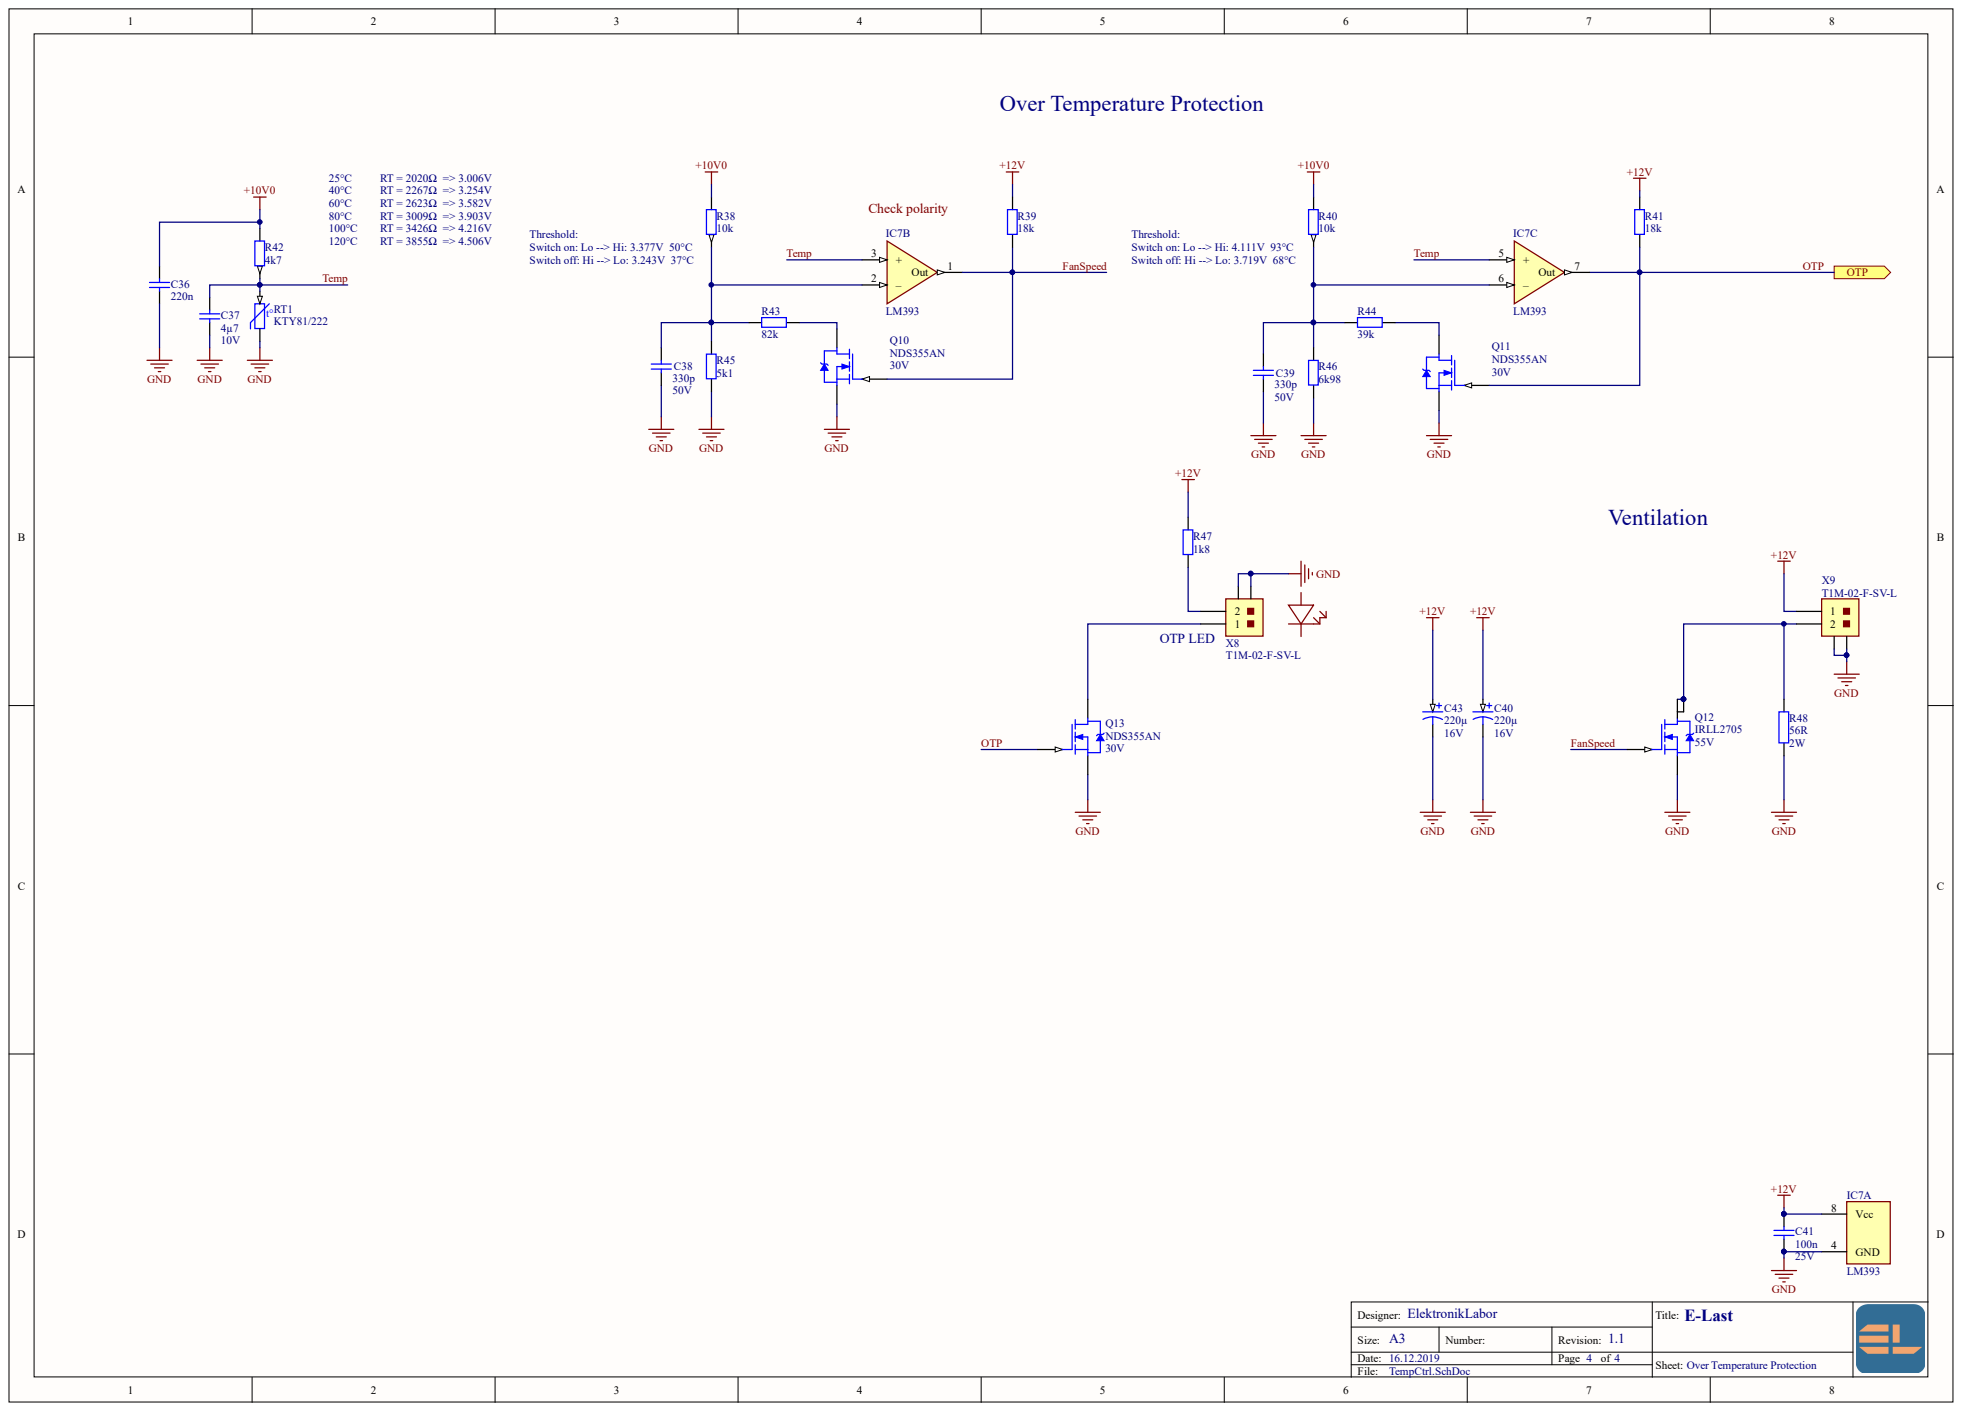
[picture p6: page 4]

Threshold:
Switch on: Lo --> Hi: 3.377V 50°C
Switch off: Hi --> Lo: 3.243V 37°C

Switch on: Lo --> Hi: 4.111V 93°C
Switch off: Hi --> Lo: 3.719V 68°C

Sheet: Over Temperature Protection
